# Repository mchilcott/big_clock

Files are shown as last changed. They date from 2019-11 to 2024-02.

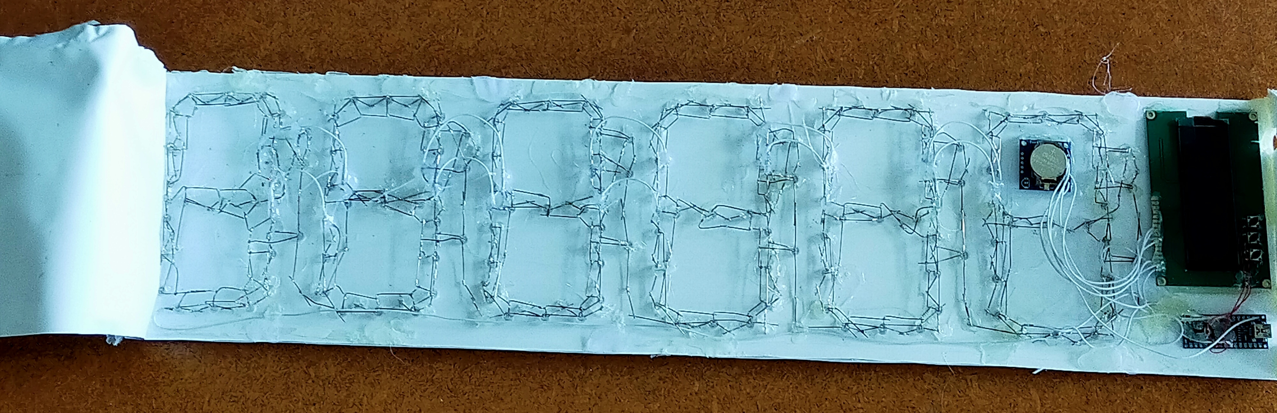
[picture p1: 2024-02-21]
doc/Photos/KoalaClockInternal.jpg

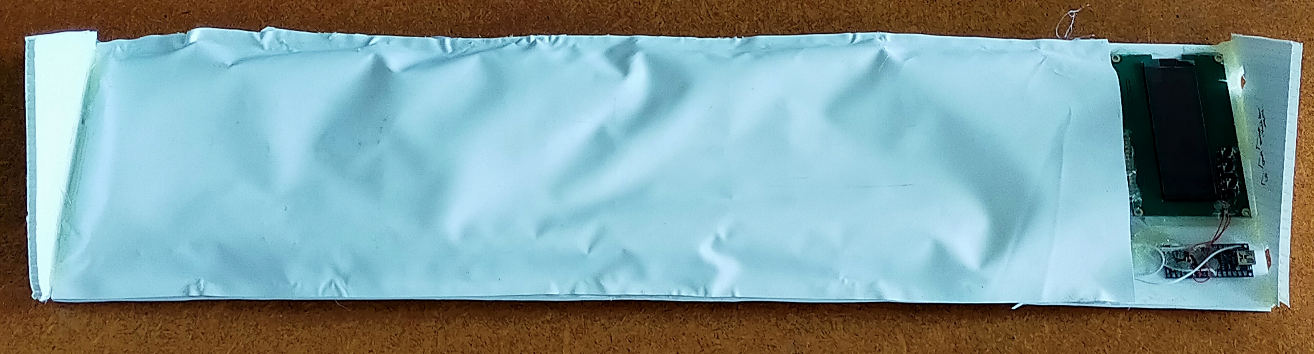
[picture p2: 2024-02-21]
doc/Photos/KoalaClockBack.jpg

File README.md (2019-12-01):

# Big Clock

This project is for a large 7-segment clock made from a series of
WS2812 LEDs. This project also uses an OLED display, 3 buttons, and a
DS1307 real-time clock.

The real-time clock keeps actual time, but the main purpose of this clock is as a count-down timer for talks at the IONS KOALA 2019 conference.

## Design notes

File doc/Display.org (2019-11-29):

* Wiring
  
  | Arduino | OLED   | Description     |
  |---------+--------+-----------------|
  | GND     | 1      | GND             |
  | 5V      | 2      | VDD, 5 V        |
  | A4      | 8 (D1) | SDA             |
  | A4      | 9 (D2) | SDA             |
  | A5      | 7 (D0) | SCL             |

  - NOTE: J0, J1, J2 on the PCB (20x4 character H02004), correspond to the
    BS (Bus Select) pins, so must be moved to get I2C going.
    (Move J2 so it is connected to ground)
    
  - RS pin on PCB is D/C# on controller

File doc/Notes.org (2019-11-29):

 
Lines are like 

    aaa
   f   b
   f   b
   f   b
    ggg
   e   c
   e   c
   e   c
    ddd
    
Bit strings: abcdefg, 1 = on

| Char | Bitstring |
|------+-----------|
| 0    |   1111110 |
| 1    |   0110000 |
| 2    |   1101101 |
| 3    |   1111001 |
| 4    |   0110011 |
| 5    |   1011011 |
| 6    |   1011111 |
| 7    |   1110000 |
| 8    |   1111111 |
| 9    |   1110011 |
| A    |   1110111 |
| b    |   0011111 |
| c    |   0001101 |
| C    |   1001110 |
| d    |   0111101 |
| E    |   1001111 |
| F    |   1000111 |
| G    |   1011110 |
| H    |   0110111 |
| h    |   0010111 |
| I    |   0000110 |
| J    |   0111100 |
| K    |   0100111 |
| L    |   0001110 |
| m    |   0010100 |
| n    |   0010101 |
| O    |   1111110 |
| o    |   0011101 |
| P    |   1100111 |
| q    |   1110011 |
| r    |   0000101 |
| S    |   1011011 |
| T    |   1000110 |
| u    |   0011100 |
| v    |   0111110 |
| w    |   0010100 |
| x    |   0100101 |
| y    |   0111011 |
| Z    |   1101101 |

This will probably work, but I was tired at the time....
There is possibly more scope for using the fact that it's not actually a 7 segment display, but oh well.
Inspiration from 
http://learningaboutelectronics.com/Articles/How-to-display-any-character-on-a-7-segment-LED-display.php
but this list is vastly better.

Note S/5, Z/2 double ups. Nothing else doubles up? uvw, nm quite indistinguishable though

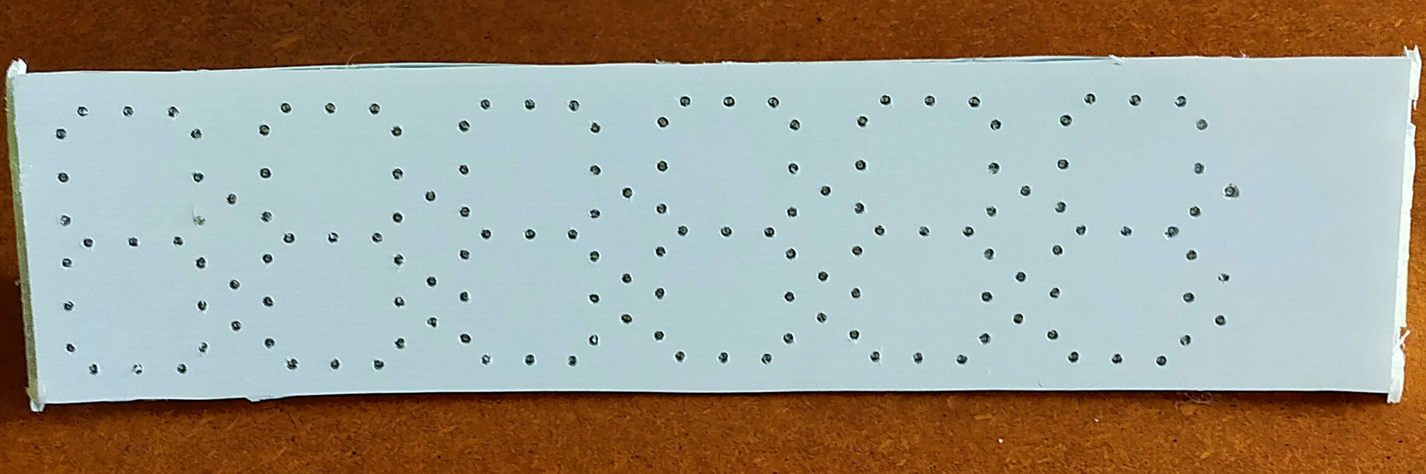
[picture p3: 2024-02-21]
doc/Photos/KoalaClockFront.jpg

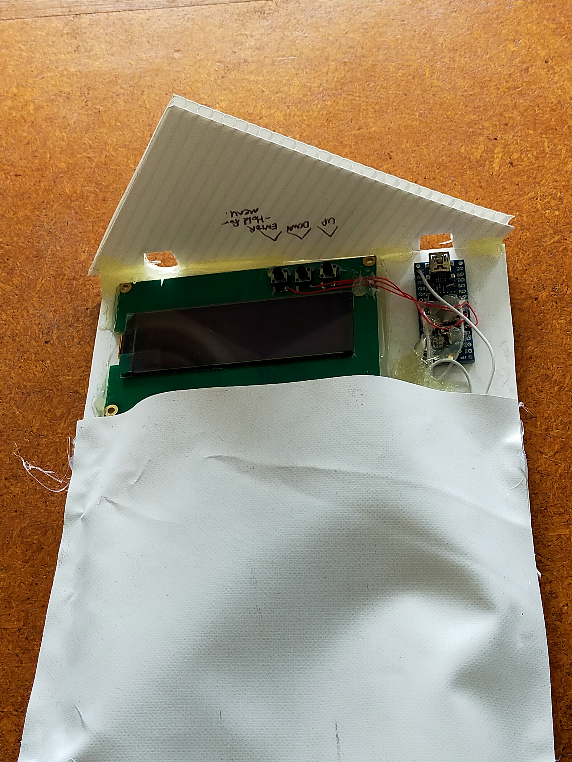
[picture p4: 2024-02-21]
doc/Photos/KoalaClockControls.jpg

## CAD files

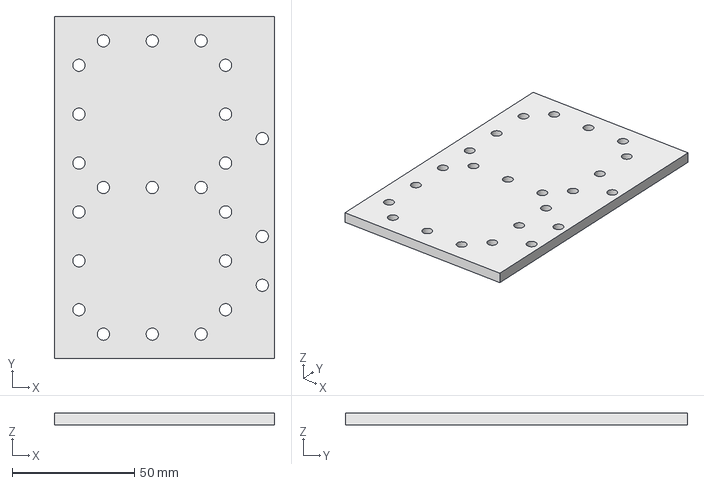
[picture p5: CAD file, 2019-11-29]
doc/Segment.FCStd
90.0 x 140.0 x 5.00 mm

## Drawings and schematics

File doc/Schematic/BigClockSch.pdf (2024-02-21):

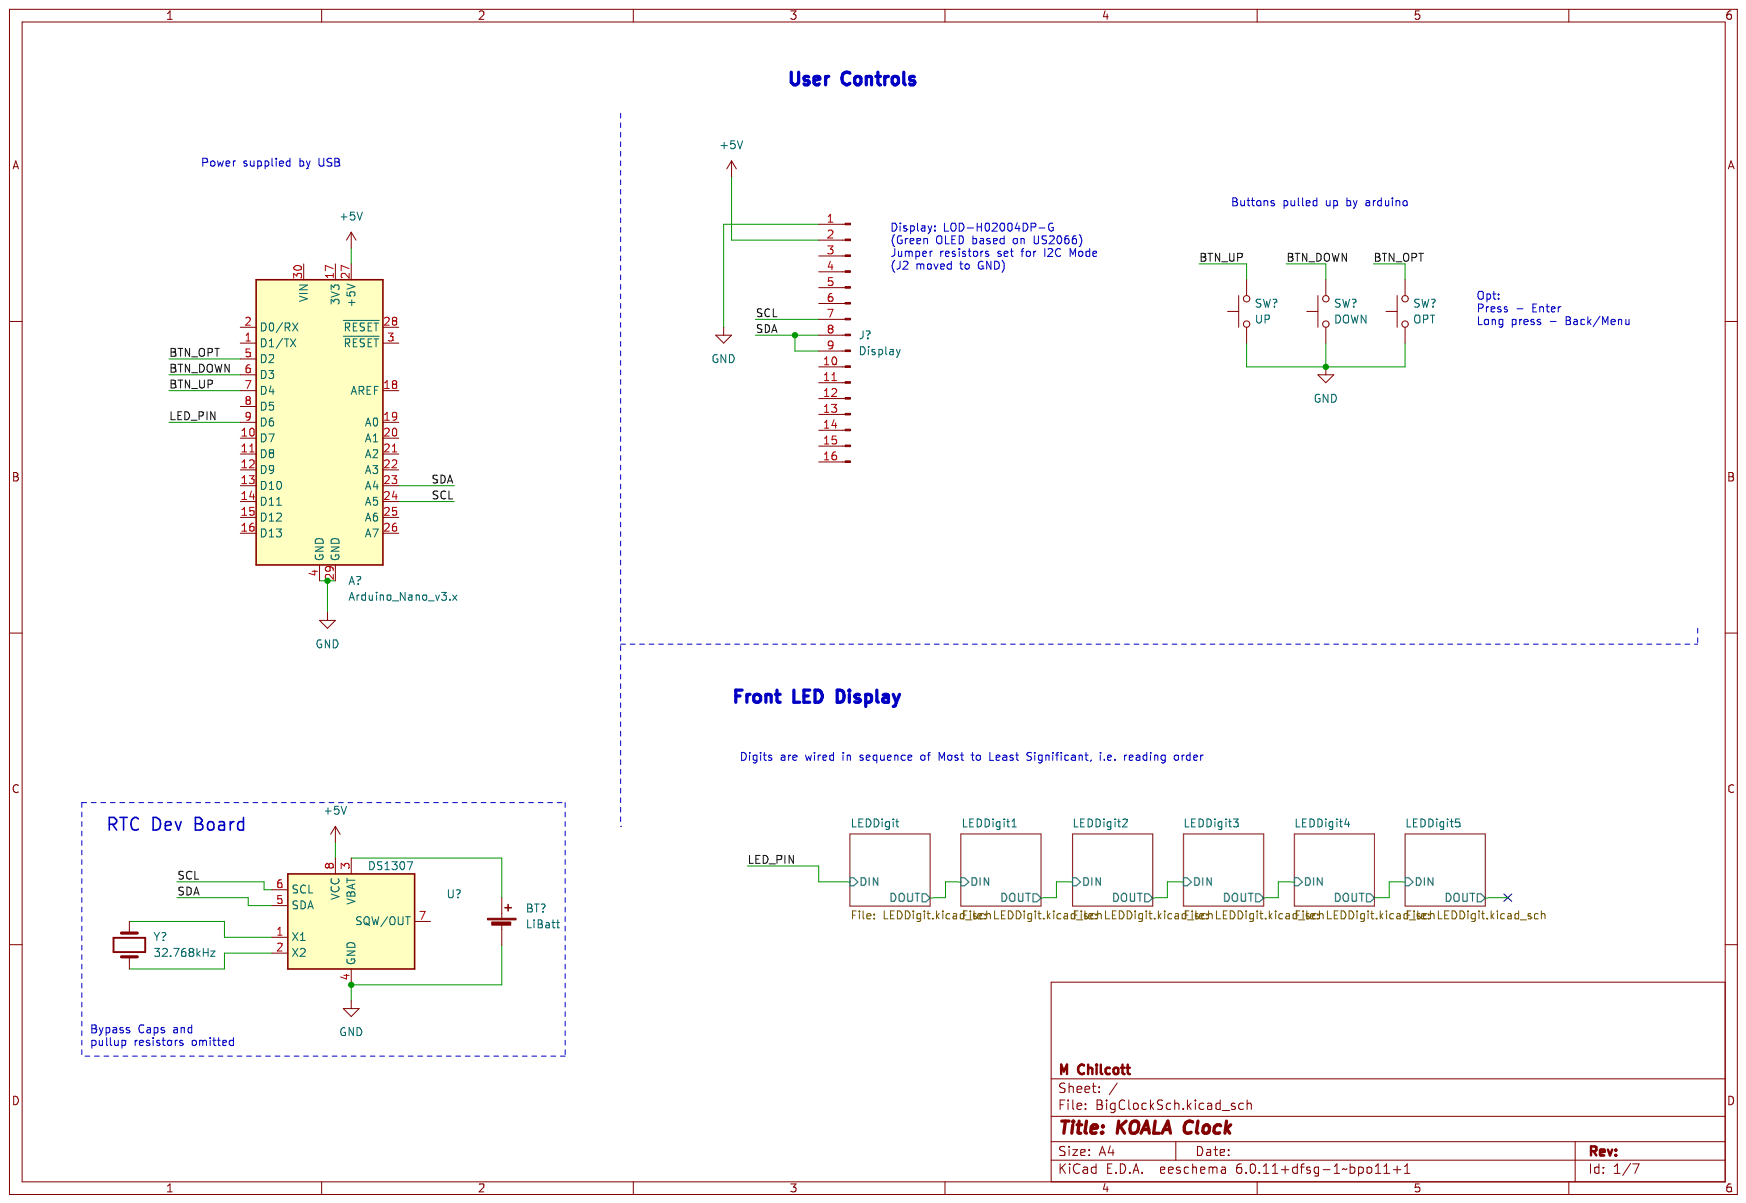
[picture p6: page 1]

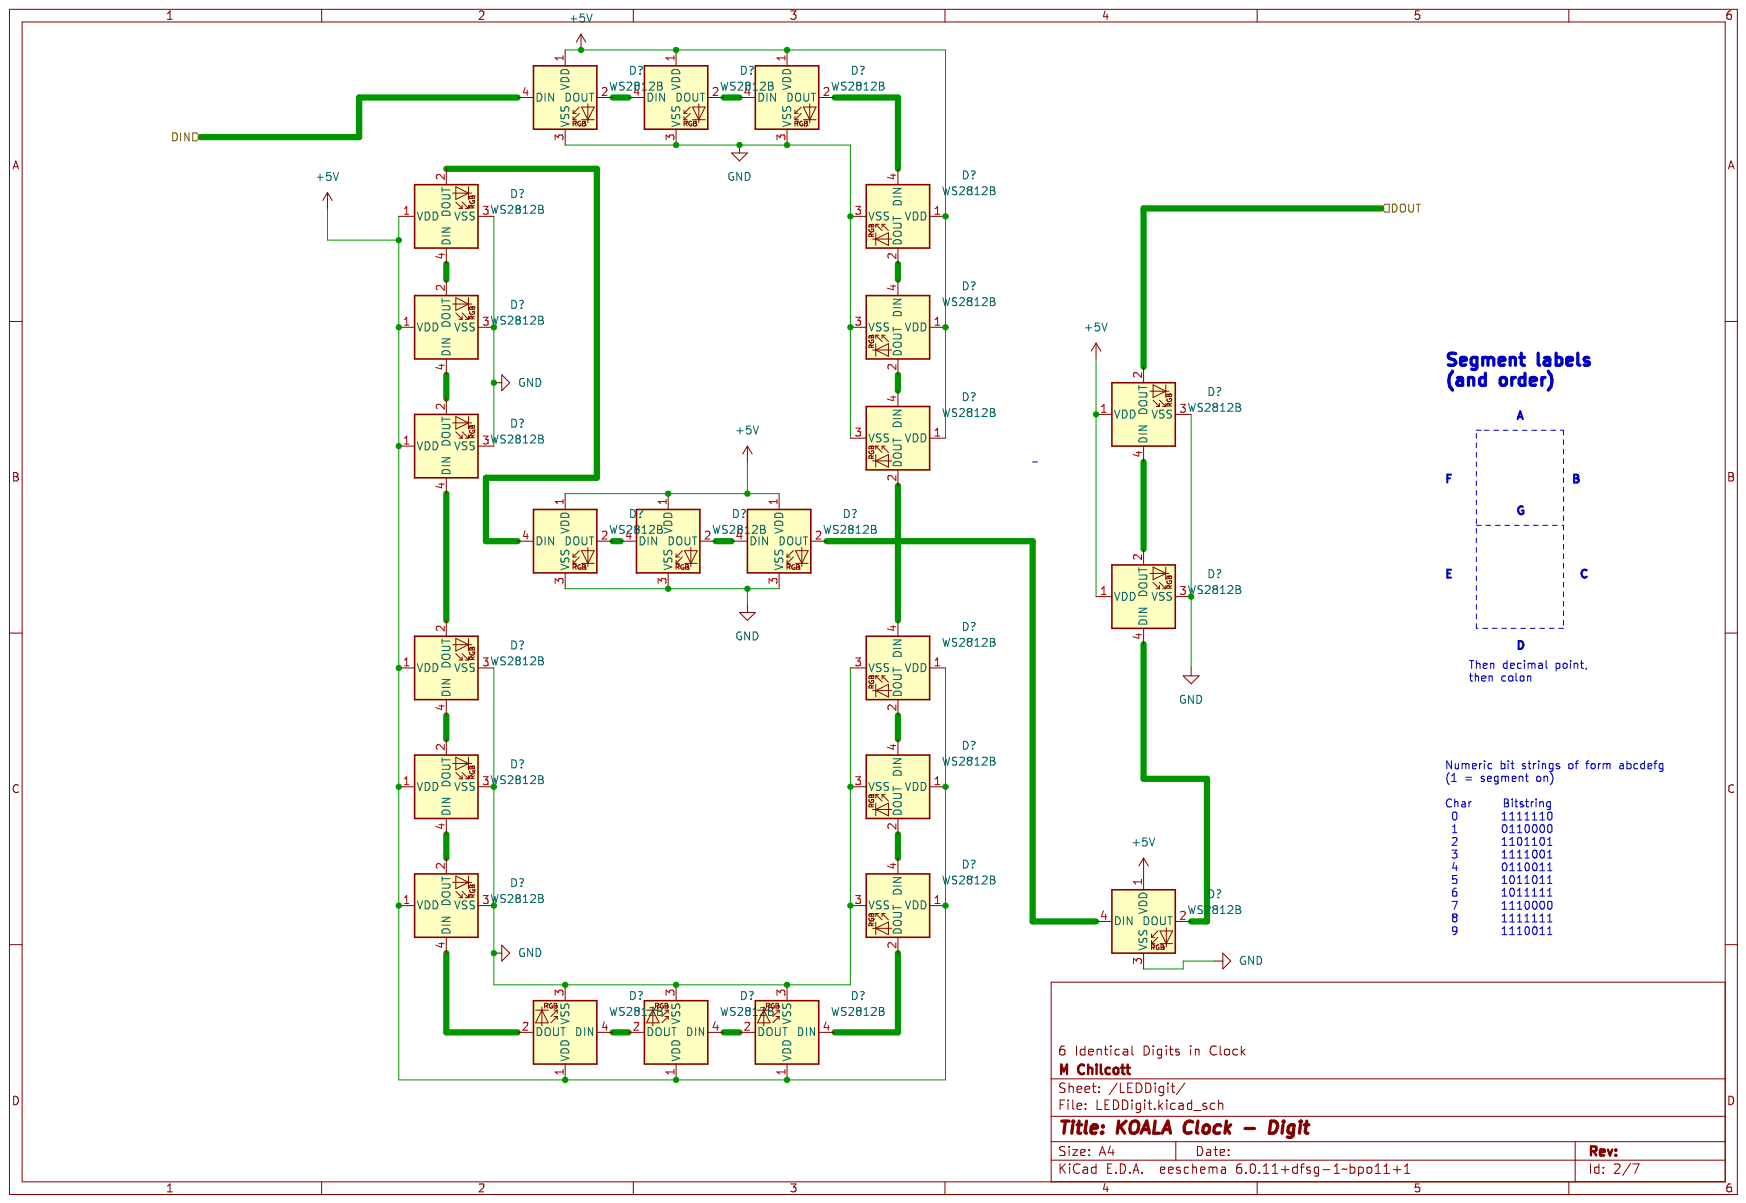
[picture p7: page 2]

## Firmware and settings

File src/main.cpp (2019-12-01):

#include <Arduino.h>

#include "OLED.h"
#include "Displays.h"
#include "HAL.h"
#include "ButtonMgr.h"

#include "ClockFace.h"
#include "FastLED.h"
#include "RTClib.h"

RTC_DS1307 rtc;


// Define the array of leds
CRGB leds[kNumLEDs];


OLED display;

WindowManager mgr (&display);

RTCClock clk;
ClockTimer tmr;
CountUp stpw;

ListMenu<8> main_menu;



// Some small functions to pass in as pointers to the managers
void up ()
{ mgr.up_evt (); Serial.println("Up");}

void dn ()
{ mgr.down_evt (); Serial.println("Down");}

void entr ()
{ mgr.enter_evt (); Serial.println("Enter");}

void bk ()
{ mgr.back_evt (); Serial.println("Back");}

ButtonMgr btn_up (BTN_UP, &up, true);
ButtonMgr btn_dn (BTN_DOWN, &dn, true);
PressHoldMgr btn_opt (BTN_OPT, &entr, &bk);


void setup ()
{
  display.init();
  Serial.begin(9600);
  
  if (! rtc.begin()) {
    display.set_point(0,0);
    display.write("Couldn't find RTC");
    while (1);
  }
  rtc.writeSqwPinMode(DS1307_SquareWave1HZ);
  
  if (! rtc.isrunning()) {
    Serial.println("RTC is NOT running!");
    // following line sets the RTC to the date & time this sketch was compiled
    rtc.adjust(DateTime(F(__DATE__), F(__TIME__)));
  }

  // Button Stuff
  pinMode(BTN_UP, INPUT);
  pinMode(BTN_DOWN, INPUT);
  pinMode(BTN_OPT, INPUT);
  digitalWrite(BTN_UP, HIGH);
  digitalWrite(BTN_DOWN, HIGH);
  digitalWrite(BTN_OPT, HIGH);

  btn_up.init();
  btn_dn.init();
  btn_opt.init();
  
  // Start up LEDs
  FastLED.addLeds<WS2812, LED_PIN, RGB>(leds, kNumLEDs);
  
  main_menu.add(&clk, "Clock");
  main_menu.add(&tmr, "Timer");
  main_menu.add(&stpw, "Stopwatch");
  mgr.load(&tmr);
}

void loop ()
{
  mgr.run();
  btn_up.check_button();
  btn_dn.check_button();
  btn_opt.check_button();
  
}

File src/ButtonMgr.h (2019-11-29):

#pragma once

#include <Arduino.h>

// Minimum button press time to check for change
#define DEBOUNCE_TIME 15

// Time till hold event emitted for PressHoldMgr
#define HOLD_TIME 600

// Button Logic levels
#define PRESSED LOW
#define RELEASED HIGH


class ButtonMgr
{
public:

 ButtonMgr(int btn_pin, void (* callback) (), bool multi_press = false):
  mPin(btn_pin),
    mMulti (multi_press)
    {
      mCallback = callback;
    }
  
  void init () {
    mLastState = digitalRead(mPin);  
  }

  virtual void check_button()
  {
    bool new_state = digitalRead(mPin);
    if(new_state == mLastState && mWaitTime == 0)
      // We are not waiting, and there has been no change
      return;

    if(new_state == mLastState && new_state == PRESSED && (signed long)(millis() - mWaitTime) > DEBOUNCE_TIME)
      {
	// We have waited
	mCallback();
	mNumCalls ++;

	if(mMulti)
	  {
	    // Decrease wait each time (hold accelerates presses)
	    int offset =  300 - (mNumCalls << 4);
	    if (offset < 0) offset = 0;
	    
	    mWaitTime = millis() + offset; // wait for press in future
	  }
	else
	  mWaitTime = 0; // Signal no longer waiting

	return;
      }

    if(new_state != mLastState)
      {
	mLastState = new_state;
	
	if(new_state == PRESSED)
	  mWaitTime = millis();
	else
	  mWaitTime  = 0;
	
	mNumCalls = 0;
      }
  }


protected:
  // Am I waiting for debounce test
  unsigned long mWaitTime;
  // Last known state of the button
  bool mLastState;
  
  // Callback function on button press
  void (* mCallback) ();

  // IO pin of button
  int mPin;

  // Should we make multiple calls if the button is held
  bool mMulti;

  // Number of callbacks for this button press
  unsigned int mNumCalls;
};



class PressHoldMgr: public ButtonMgr
{
public:

  PressHoldMgr (int pin_num, void (* callback)(), void (* hold_callback)()):
    ButtonMgr(pin_num, callback, false),
    mCallOnRelease(false)
  {mHoldCallback = hold_callback;}
 
  virtual void check_button ()
    {
    bool new_state = digitalRead(mPin);
    
    if(new_state == RELEASED && mLastState == RELEASED)
      // Button not pressed
      return;
    
    if(new_state == mLastState && new_state == PRESSED && millis() - mWaitTime > HOLD_TIME && mNumCalls == 0)
      {
	// We have waited so long that this is a hold event, and this hasn't been called before
	mHoldCallback();
	mNumCalls ++;

        mWaitTime = 0; // Signal no longer waiting
        mCallOnRelease = false;
	return;
      }
    else if (new_state == mLastState && new_state == PRESSED && millis() - mWaitTime > DEBOUNCE_TIME && mNumCalls == 0)
      {
        // Waited for debounce, and we haven't already called the hold function
        mCallOnRelease = true;
        return;
      }

    // Handle changes
    if(new_state != mLastState)
      {
	mLastState = new_state;
	
	if(new_state == PRESSED)
	  mWaitTime = millis();
	else
          {
	  mWaitTime = 0;
          if(mCallOnRelease)
            mCallback();
          mCallOnRelease = false;
          }
	
	mNumCalls = 0;
      }
  }

private:
  // Callback for hold
  void (* mHoldCallback) ();

  // Will we make a call on button release? (i.e. have we not held too long)
  bool mCallOnRelease;

};

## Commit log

2019-11-29 Working ish clock
    [Segment.FCStd]
2019-11-30 Added support for an RTC to keep the time. Not yet used for the count up/down timers
2019-12-01 More extensions to the Timer, geared towards KOALA
2024-02-20 Added partial schematic
    [BigClockSch.kicad_pcb, BigClockSch.kicad_sch, LEDDigit.kicad_sch]
2024-02-21 Schematic finished, and added photos
    [BigClockSch.kicad_sch, LEDDigit.kicad_sch]
2024-02-21 Added PDF of Schematic
    [BigClockSch.kicad_sch, LEDDigit.kicad_sch]
